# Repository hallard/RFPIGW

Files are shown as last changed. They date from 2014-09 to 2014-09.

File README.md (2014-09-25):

RFM12B RFM69CW Raspberry Pi Gateway With OLED and OOK
=====================================================

This is a simple board to be able to 
- Receive RFM12B data
- Receive RFM69CW data
- Blink 1st led when receiving from 1st module
- Blink 2nd led when receiving from 2nd module
- Display whatever on I2C OLED LCD
- Ready for OOK send/receive (see [jeelabs][5] for how to)

This is the 2nd proto board, I've ordered one on OSHPark, assembled 
then and it works fine so far. In this new version I've flipped the 
OLED since on some enclosure it was impossible to close them due to 
the total thickness of the board + OLED over it.

This version replace the 1.1 version which had some wiring reversed 
(MOSI/MISO) on the bottom module. I've also put the crystal on top 
side of the PCB instead of the bottom

No firmware or documentation is released because I'm currently working on 
project that will use this board as a gateway and I will release all source
code and documentation in the same time.
But you can take a look to this new project [Ultra Low Power Wireless Arduino Node][3]

This board gateway should work with the official firmware of [RFM2PI][6]
board dedicated for emoncms with small tweaking.

Check out news and other projects on my [blog][4]

Detailed Description
====================

Everything will be documented on my [blog][4]

**Schematic**  
schematic

**Boards**  
board&nbsp;
top&nbsp;
bottom

[3]: http://hallard.me/bp-ulpnode/
[4]: http://hallard.me
[5]: http://jeelabs.net/projects/cafe/wiki/Receiving_OOKASK_with_a_modified_RFM12B
[6]: http://wiki.openenergymonitor.org/index.php?title=RFM12Pi_V2

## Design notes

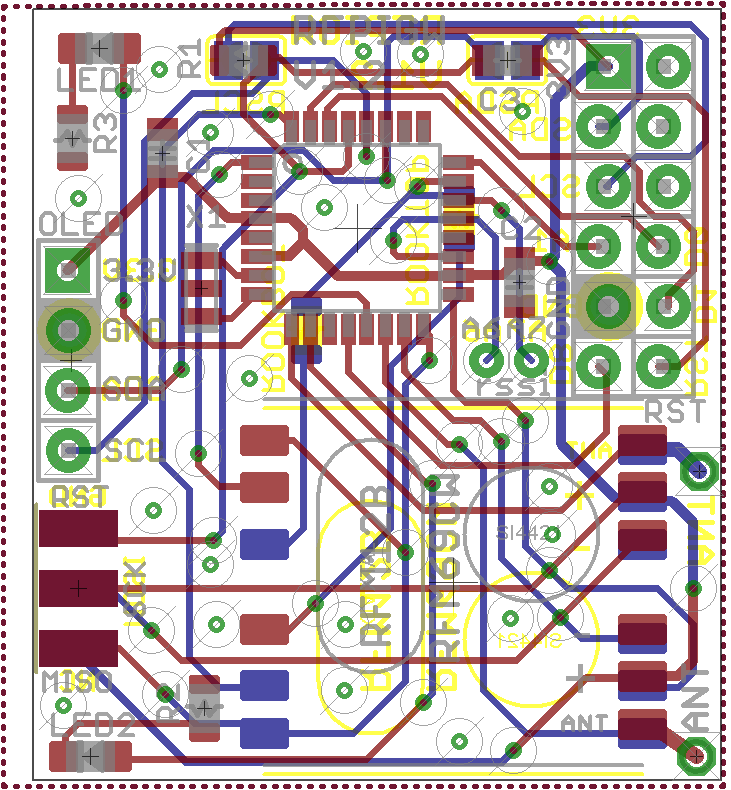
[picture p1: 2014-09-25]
RFPIGW-brd.png

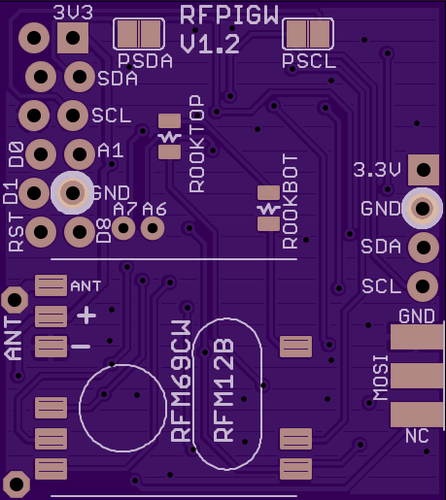
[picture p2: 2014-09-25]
RFPIGW-bottom.png

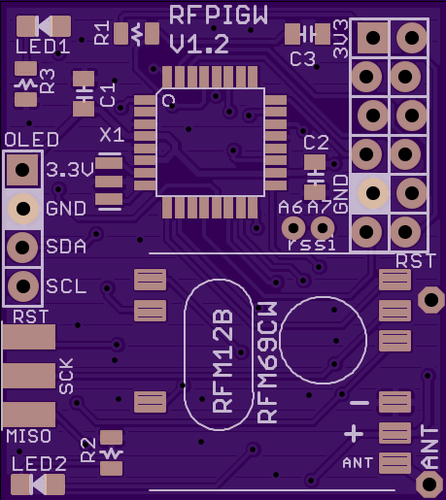
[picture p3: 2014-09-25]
RFPIGW-top.png

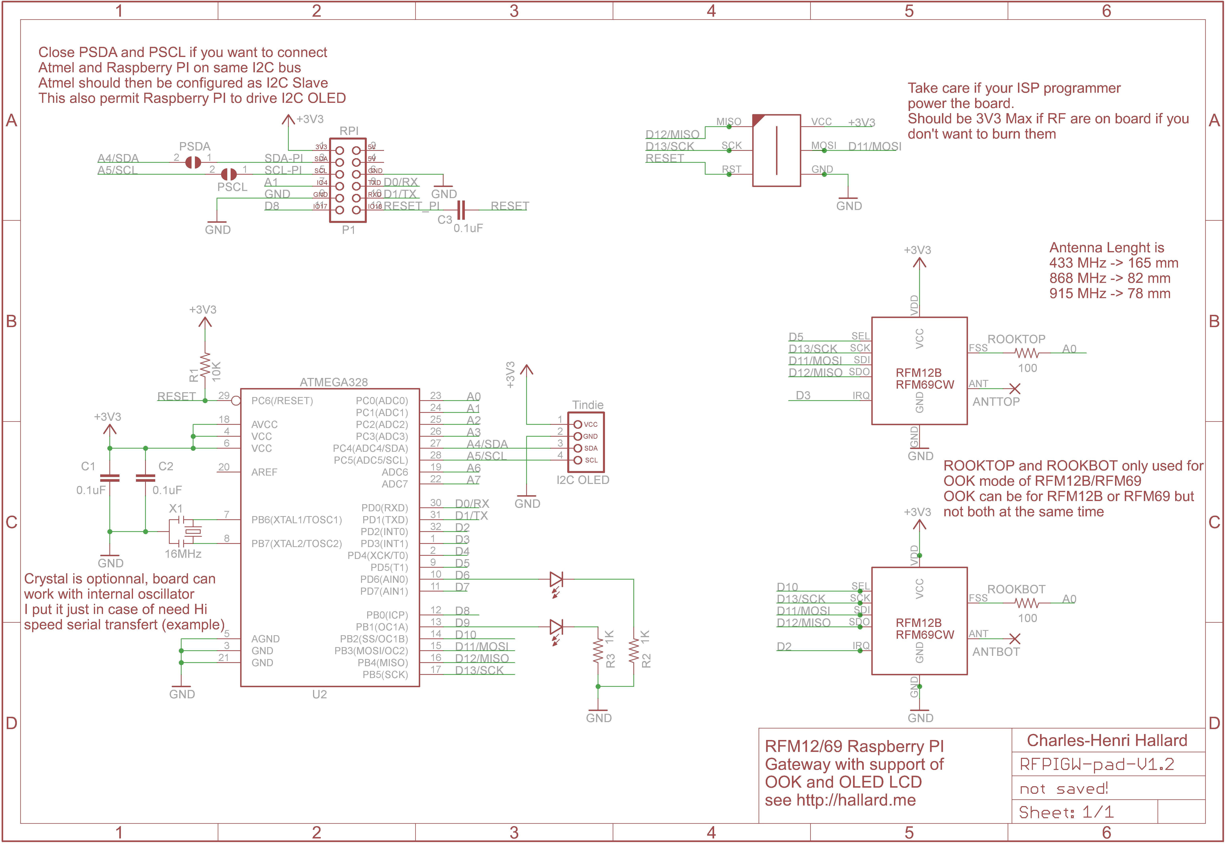
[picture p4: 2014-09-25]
RFPIGW-sch.png

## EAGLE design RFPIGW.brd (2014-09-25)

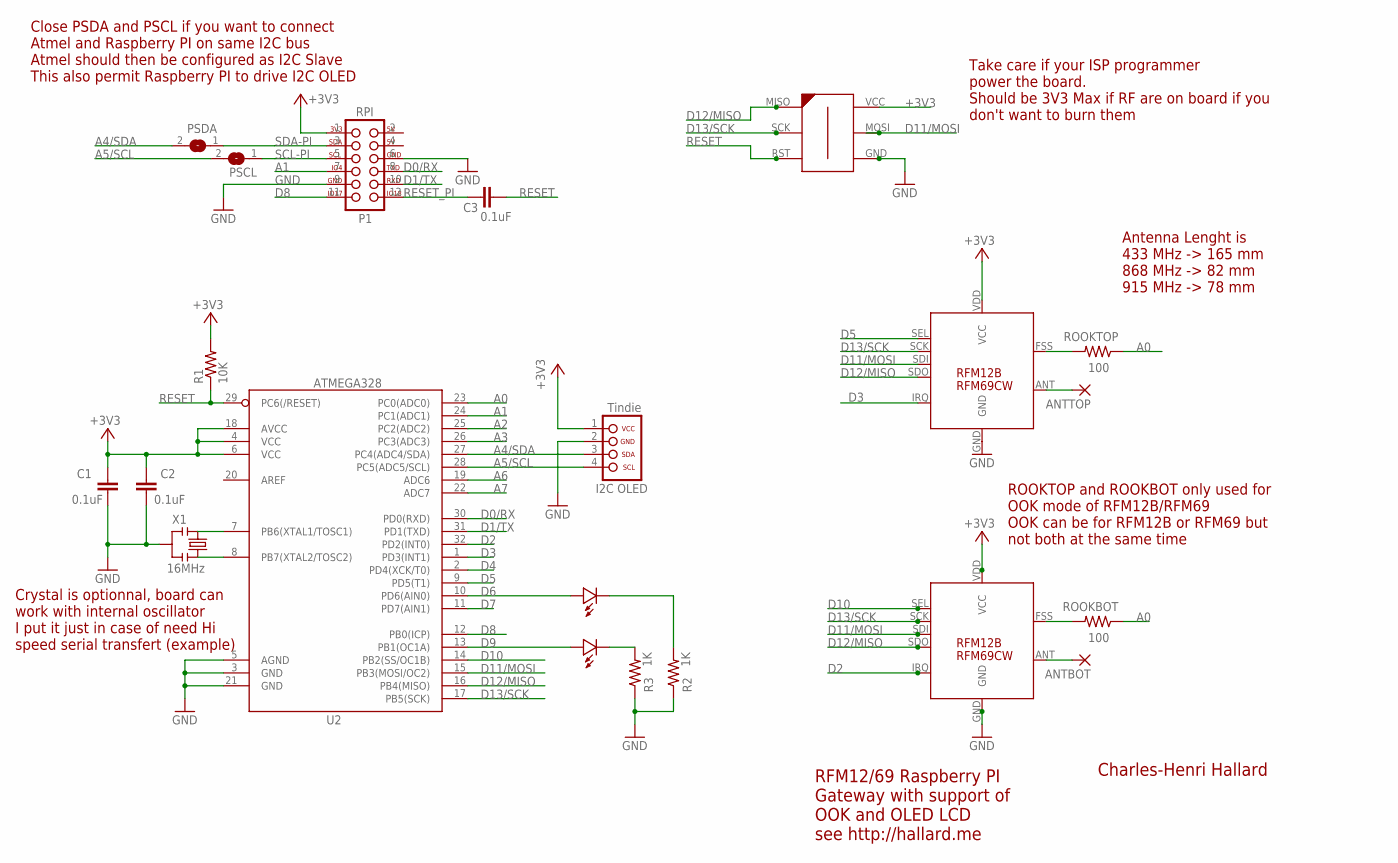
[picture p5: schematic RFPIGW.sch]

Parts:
ANTBOT: 1,6/0,8
ANTTOP: 1,6/0,8
C1, C2, C3: 0.1uF; 0805-CAP
LED1, LED2: LED0805-LARGE; 0805-LED-LARGEPADS
OLED: OLED_I2C_TINDIE; 1X04_NO_LOCK
PSCL: SJ
PSDA: SJ
R1: 10K; 0805-RES
R2, R3: 1K; 0805-RES
ROOKBOT: 100; 0805-RES
ROOKTOP: 100; 0805-RES
U2: ATMEGA328; TQFP32-08
U$1: PI P1; 2X06_LOCK
U$2, U$3: RFM12B; RFM12B-MINPADS
U$4: AVR-ISP-6-EDGE; 6PAD_ISP
X1: 16MHz; RESONATOR-SMD

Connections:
2: U$1.2
4: U$1.4
+3V3: C1.1, C2.1, OLED.1 (VCC), R1.2, U2.4 (VCC), U2.6 (VCC), U2.18 (AVCC), U$1.1, U$2.VDD (VCC), U$3.VDD (VCC), U$4.VCC
A0: ROOKBOT.1, ROOKTOP.1, U2.23 (PC0(ADC0))
A1: U2.24 (PC1(ADC1)), U$1.7
A2: U2.25 (PC2(ADC2))
A3: U2.26 (PC3(ADC3))
A4/SDA: OLED.3 (SDA), PSDA.2, U2.27 (PC4(ADC4/SDA))
A5/SCL: OLED.4 (SCL), PSCL.2, U2.28 (PC5(ADC5/SCL))
A6: U2.19 (ADC6)
A7: U2.22 (ADC7)
D0/RX: U2.30 (PD0(RXD)), U$1.8
D1/TX: U2.31 (PD1(TXD)), U$1.10
D2: U2.32 (PD2(INT0)), U$2.IRQ
D3: U2.1 (PD3(INT1)), U$3.IRQ
D4: U2.2 (PD4(XCK/T0))
D5: U2.9 (PD5(T1)), U$3.SEL
D6: LED2.PLUS, U2.10 (PD6(AIN0))
D7: U2.11 (PD7(AIN1))
D8: U2.12 (PB0(ICP)), U$1.11
D9: LED1.PLUS, U2.13 (PB1(OC1A))
D10: U2.14 (PB2(SS/OC1B)), U$2.SEL
D11/MOSI: U2.15 (PB3(MOSI/OC2)), U$2.SDI, U$3.SDI, U$4.MOSI
D12/MISO: U2.16 (PB4(MISO)), U$2.SDO, U$3.SDO, U$4.MISO
D13/SCK: U2.17 (PB5(SCK)), U$2.SCK, U$3.SCK, U$4.SCK
GND: C1.2, C2.2, OLED.2 (GND), R2.1, R3.1, U2.3 (GND), U2.5 (AGND), U2.21 (GND), U$1.6, U$1.9, U$2.GND, U$3.GND, U$4.GND, X1.2
unnamed: ROOKBOT.2, U$2.FSS (FFS)
unnamed: ANTTOP.1, U$3.ANT
unnamed: LED1.MINUS, R3.2
unnamed: ROOKTOP.2, U$3.FSS (FFS)
unnamed: U2.7 (PB6(XTAL1/TOSC1)), X1.1
unnamed: ANTBOT.1, U$2.ANT
unnamed: U2.8 (PB7(XTAL2/TOSC2)), X1.3
unnamed: LED2.MINUS, R2.2
RESET: C3.2, R1.1, U2.29 (PC6(/RESET)), U$4.RST
RESET_PI: C3.1, U$1.12
SCL-PI: PSCL.1, U$1.5
SDA-PI: PSDA.1, U$1.3

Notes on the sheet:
RFM12/69 Raspberry PI Gateway with support of OOK and OLED LCD see http://hallard.me
Charles-Henri Hallard
Antenna Lenght is 433 MHz -> 165 mm 868 MHz -> 82 mm 915 MHz -> 78 mm
ROOKTOP and ROOKBOT only used for OOK mode of RFM12B/RFM69 OOK can be for RFM12B or RFM69 but not both at the same time
Close PSDA and PSCL if you want to connect Atmel and Raspberry PI on same I2C bus Atmel should then be configured as I2C Slave This also permit Raspberry PI to drive I2C OLED
Take care if your ISP programmer power the board. Should be 3V3 Max if RF are on board if you don't want to burn them
Crystal is optionnal, board can work with internal oscillator I put it just in case of need Hi speed serial transfert (example)
RFM69CW

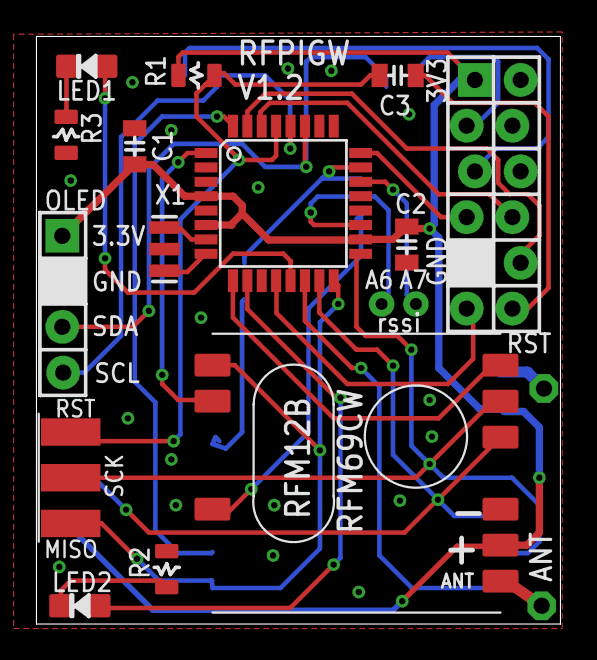
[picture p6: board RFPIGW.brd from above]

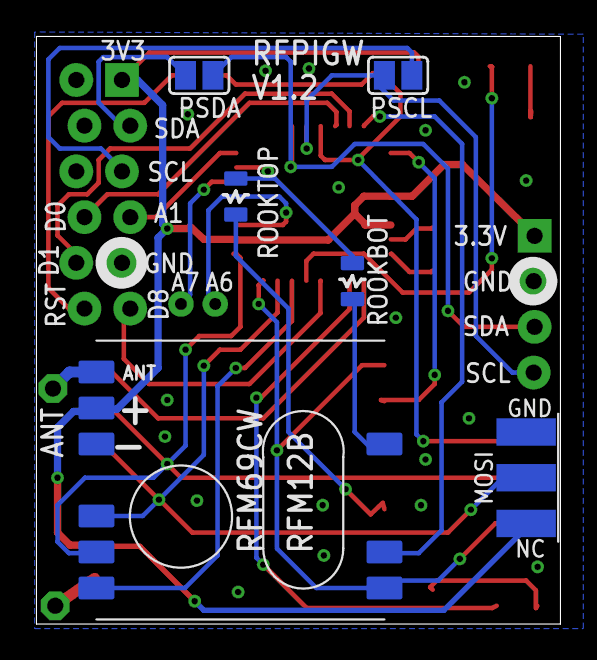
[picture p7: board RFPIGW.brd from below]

Board: 2 copper layers, 29.1 x 32.6 mm, 21 parts (5 on the bottom side), 30 nets.

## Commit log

2014-02-13 Creation
    First Commit, PCB and Stencil sent to FAB with this version
    [RFPIGW.brd, RFPIGW.sch]
2014-02-13 Minor Fix
    [RFPIGW.brd]
2014-09-25 Updated to V1.2
    [RFPIGW.brd, RFPIGW.sch]

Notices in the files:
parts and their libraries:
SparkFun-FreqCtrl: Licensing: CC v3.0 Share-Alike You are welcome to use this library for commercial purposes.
